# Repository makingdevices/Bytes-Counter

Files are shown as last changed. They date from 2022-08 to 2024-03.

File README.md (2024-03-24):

<!-- Improved compatibility of back to top link: See: https://github.com/othneildrew/Best-README-Template/pull/73 -->

<!--
*** Thanks for checking out the Best-README-Template. If you have a suggestion
*** that would make this better, please fork the repo and create a pull request
*** or simply open an issue with the tag "enhancement".
*** Don't forget to give the project a star!
*** Thanks again! Now go create something AMAZING! :D
-->

<!-- PROJECT SHIELDS -->
<!--
*** I'm using markdown "reference style" links for readability.
*** Reference links are enclosed in brackets [ ] instead of parentheses ( ).
*** See the bottom of this document for the declaration of the reference variables
*** for contributors-url, forks-url, etc. This is an optional, concise syntax you may use.
*** https://www.markdownguide.org/basic-syntax/#reference-style-links
-->
[][ig-url]
[][sponsor-url]
[][stars-url]
[][issues-url]
[][linkedin-url]

<!-- PROJECT LOGO -->
<br />
<div align="center">
  <a href="https://makingdevices.com/links/">
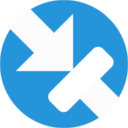
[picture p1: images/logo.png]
    
  </a>

<h3 align="center">Making Devices</h3>

  <p align="center">
    Open Source projects where we struggle with engineering, electronics, coding and who knows what else... In this case, Bytes Counter is a very simple digital tally counter, so hopefully you may find it interesting ;)
  </p>
</div>

<!-- TABLE OF CONTENTS -->
<details>
  <summary>Table of Contents</summary>
  <ol>
    <li>
      <a href="#about-the-project">About The Project</a>
      <ul>
        <li><a href="#built-with">Built With</a></li>
      </ul>
    </li>
    <li>
      <a href="#Build-one">Build one</a>
      <ul>
      </ul>
    </li>
    <li><a href="#usage">Usage</a></li>
    <li><a href="#roadmap">Roadmap</a></li>
    <li><a href="#license">License</a></li>
    <li><a href="#contact">Contact</a></li>
    <li><a href="#Sponsor">Sponsor</a></li>
  </ol>
</details>

<!-- ABOUT THE PROJECT -->
## About The Project

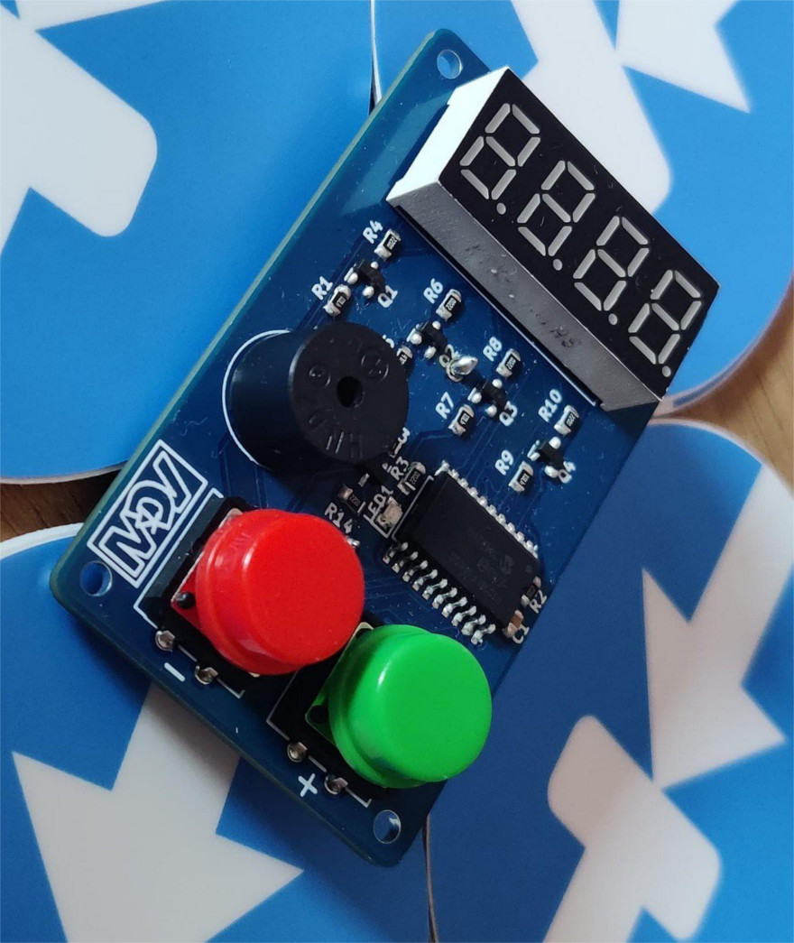
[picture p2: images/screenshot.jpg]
Bytes Counter Shot
[](https://makingdevices.com/Bytes-Counter)

Bytes Counter is a simple Tally Counter for counting people in places, helping you in inventories, practising soldering or just counting things at work! The project was chosen to test some PCB manufacturer capabilities and experiment with both the XLP (Extreme Low-Power Technology) and the pic18LF14k50 itself

The PCB does not have any power button, since the project's approach is to use the XLP technology of the PIC. It only has two buttons: increase/decrease the count.

A buzzer helps you count anything without needing to read the display every time so that you can focus on your work.

Even after weeks or months, the count is kept while in deep sleep mode.

<p align="right">(<a href="#readme-top">back to top</a>)</p>

### Built With

[][PIC-url]
[][MPLAB-C-url]
[][kicad-url]
[][sponsor-url]

<p align="right">(<a href="#readme-top">back to top</a>)</p>

<!-- GETTING STARTED -->

## Build one

1. Get the gerber files for the latest version: [V1](https://github.com/makingdevices/Bytes-Counter/blob/main/v1/Gerber/BytesCounterV1.zip) 
2. Send them to a PCB manufacturer ([Our Sponsor is PCBWAY][sponsor-url])
3. Buy all the components from the [Bill Of Materials](https://github.com/makingdevices/Bytes-Counter/blob/main/v1/BytesCounter_BOM.xlsx)
4. Solder everything with the help of the [schematic](https://github.com/makingdevices/Bytes-Counter/blob/main/v1/schematicv1.pdf)
5. Burn the [latest firmware](https://github.com/makingdevices/Bytes-Counter/blob/main/v1/Simulation/Bytes_Counter.hex)
6. Give us a Star to the respository ;)

Here it is an assembly video:

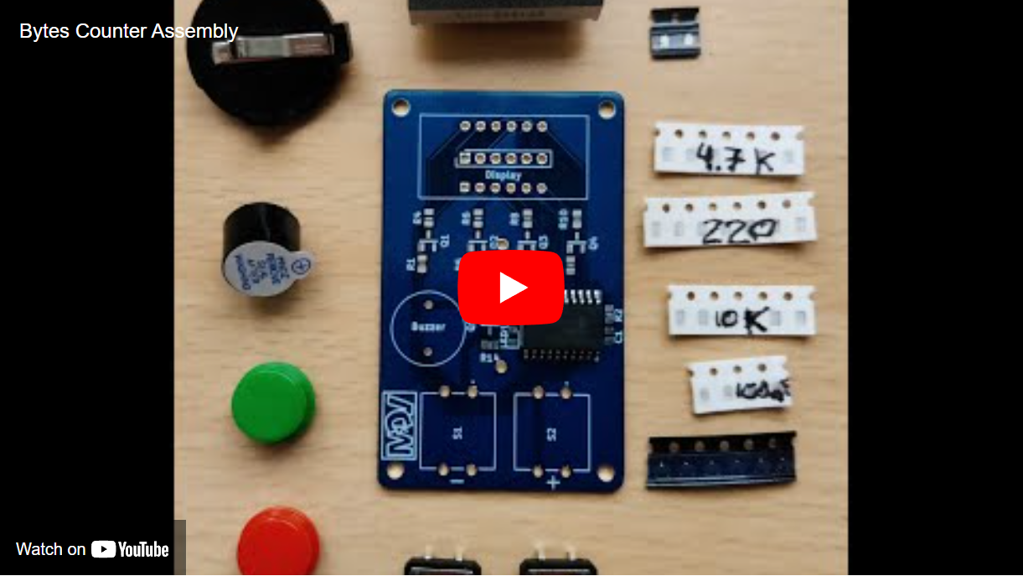
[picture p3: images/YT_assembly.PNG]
Assembly Shot
[](https://www.youtube.com/watch?v=Gu0cR_CFLYs)

<p align="right">(<a href="#readme-top">back to top</a>)</p>

<!-- USAGE EXAMPLES -->
## Usage

Instructions of use:

- Pressing "+" or "-" will increase/decrease the count.
- Long press "+" : Sound Event -> Activate/Deactivate buzzer sounds.
- Long press "-" : Reset event -> Reset the count.
- 60s without pressing any button: Deep Sleep Mode -> Display off.
- Any button pulsation will exit Deep Sleep Mode.

<p align="right">(<a href="#readme-top">back to top</a>)</p>

<!-- ROADMAP -->
## Roadmap

- [x] Count up/down and show it on screen
- [x] enable/disable sound when pressing buttons
- [x] Low Power Consumption
    - [x] Lower the frequency of the microcontroller at minimum
    - [x] Enter deep sleep mode automatically

See the [open issues](https://github.com/makingdevices/Bytes-Counter/issues) for a full list of proposed features (and known issues).

State: Project <b>FINISHED</b> - 01/08/2022

<p align="right">(<a href="#readme-top">back to top</a>)</p>

<!-- LICENSE -->
## License

Distributed under three licenses:
- [Hardware](/License/HW_cern_ohl_s_v2.pdf)
- [Software](/License/SW_GPLv3.0.txt)
- [Documentation](/License/Documentation_CC-BY-SA-4.0.txt)

[GPL v3 License][license-url] 
<p align="right">(<a href="#readme-top">back to top</a>)</p>

<!-- CONTACT -->
## Contact

Making Devices - [@MakingDevices](https://www.instagram.com/makingdevices/)

Project Link: [https://github.com/makingdevices/Bytes-Counter](https://github.com/makingdevices/Bytes-Counter)

Other Links: [LinkTree](https://makingdevices.com/links/)

<p align="right">(<a href="#readme-top">back to top</a>)</p>

<!-- Sponsor -->
## Sponsor

[PCBWAY](https://www.pcbway.com/?from=makingdevices) helped us with the fabrication of the PCBs. You can check their quality with the following pictures:

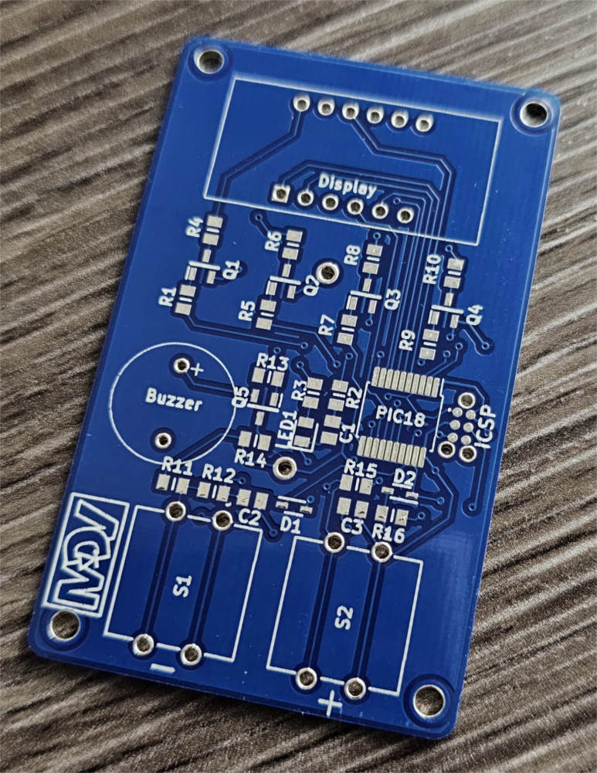
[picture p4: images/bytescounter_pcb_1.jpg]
PCB Shot 1
[](https://www.pcbway.com/?from=makingdevices)
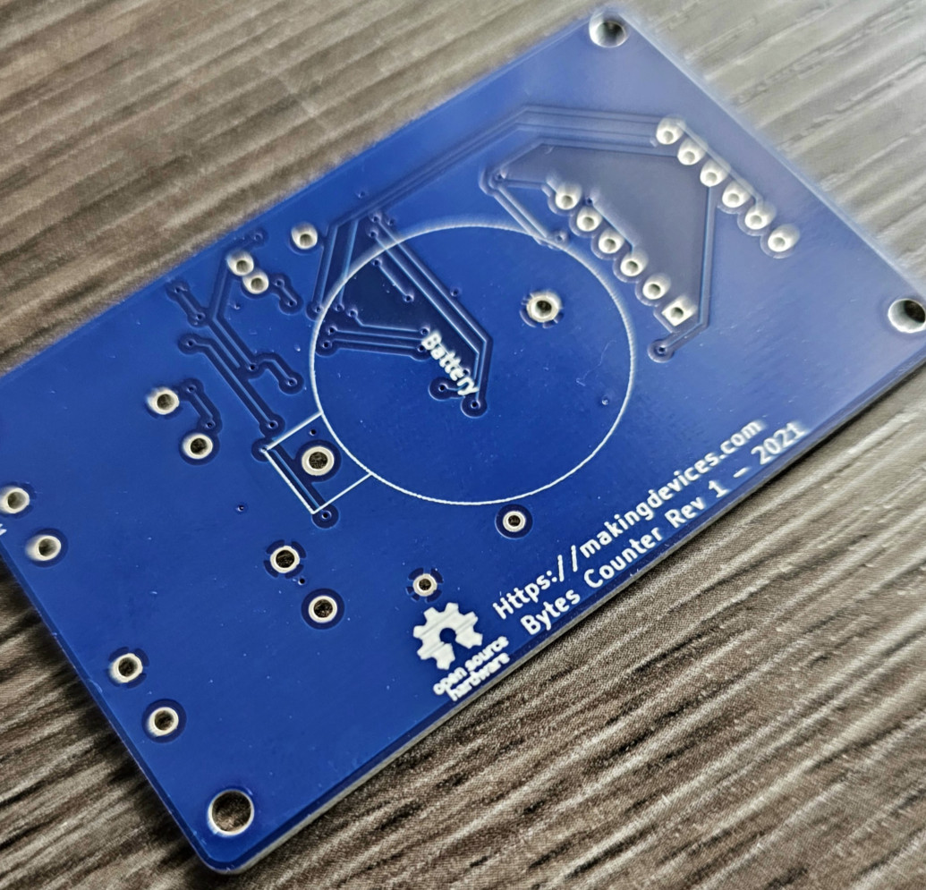
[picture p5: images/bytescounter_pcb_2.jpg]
PCB Shot 2
[](https://www.pcbway.com/?from=makingdevices)

Should you want to colaborate with MakingDevices, you can buy a [BytesCounter fully assembled and ready to use](https://www.pcbway.com/project/gifts_detail/Bytes_Counter_v1_0_4c88cb45.html) ;).

<p align="right">(<a href="#readme-top">back to top</a>)</p>

<!-- MARKDOWN LINKS & IMAGES -->
<!-- https://www.markdownguide.org/basic-syntax/#reference-style-links -->
[contributors-shield]: https://img.shields.io/github/contributors/makingdevices/Bytes-Counter.svg?style=for-the-badge
[contributors-url]: https://github.com/makingdevices/Bytes-Counter/graphs/contributors
[forks-shield]: https://img.shields.io/github/forks/makingdevices/Bytes-Counter.svg?style=for-the-badge
[forks-url]: https://github.com/makingdevices/Bytes-Counter/network/members
[stars-shield]: https://img.shields.io/github/stars/makingdevices/Bytes-Counter.svg?style=for-the-badge
[stars-url]: https://github.com/makingdevices/Bytes-Counter/stargazers
[issues-shield]: https://img.shields.io/github/issues/makingdevices/Bytes-Counter.svg?style=for-the-badge
[issues-url]: https://github.com/makingdevices/Bytes-Counter/issues
[license-shield]: /images/license.png
[license-url]: https://github.com/makingdevices/Bytes-Counter/tree/main/License
[linkedin-shield]: https://img.shields.io/badge/-LinkedIn-black.svg?style=for-the-badge&logo=linkedin&colorB=555
[linkedin-url]: https://www.linkedin.com/company/making-devices/
[sponsor-shield]: https://img.shields.io/badge/SPONSOR-PCBWAY-black.svg?style=for-the-badge&colorB=1200
[sponsor-url]: https://www.pcbway.com/?from=makingdevices
[sponsor-screenshot]: /images/PCB_sponsor.png
[product-screenshot]: images/screenshot.jpg
[pcb_pic1]: images/bytescounter_pcb_1.jpg
[pcb_pic2]: images/bytescounter_pcb_2.jpg
[PIC]: https://img.shields.io/badge/PIC18LF14K50-000000?style=for-the-badge
[PIC-url]: http://ww1.microchip.com/downloads/en/devicedoc/40001350f.pdf
[kicad-shield]: https://img.shields.io/badge/kicad-0b03fc?style=for-the-badge&logo=kicad&logoColor=white
[kicad-url]: https://www.kicad.org/
[YT-screenshot]: images/YT_assembly.PNG
[sponsor-icon]:  https://img.shields.io/badge/-PCBWAY-black.svg?style=for-the-badge&colorB=1200
[ig-shield]: https://img.shields.io/badge/instagram-a83297?style=for-the-badge&logo=instagram&logoColor=white
[ig-url]: https://www.instagram.com/makingdevices/
[MPLAB-C]: https://img.shields.io/badge/MPLAB%20C18-DD0031?style=for-the-badge&logo=C&logoColor=white
[MPLAB-C-url]: https://www.microchip.com/en-us/development-tool/SW006011
[Svelte.dev]: https://img.shields.io/badge/Svelte-4A4A55?style=for-the-badge&logo=svelte&logoColor=FF3E00
[Svelte-url]: https://svelte.dev/
[Laravel.com]: https://img.shields.io/badge/Laravel-FF2D20?style=for-the-badge&logo=laravel&logoColor=white
[Laravel-url]: https://laravel.com
[Bootstrap.com]: https://img.shields.io/badge/Bootstrap-563D7C?style=for-the-badge&logo=bootstrap&logoColor=white
[Bootstrap-url]: https://getbootstrap.com
[JQuery.com]: https://img.shields.io/badge/jQuery-0769AD?style=for-the-badge&logo=jquery&logoColor=white
[JQuery-url]: https://jquery.com

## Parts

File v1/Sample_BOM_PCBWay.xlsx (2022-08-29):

 |  |  |  | Bytes Counter v1 BOM (Sample Bill of Materials)
Item # | *Designator | *Qty | Layer | Manufacturer | *Mfg Part # | Description / Value | *Package/Footprint | Type | Your Instructions / Notes | Price
1 | IC1 | 1 | top | Microchip | PIC18LF14K50T-I/SS | MicroProcessor | 20-SSOP | SMD | It has to be the official part
2 | LED1 | 1 | top | TOGIALED | TJ-S2012SW8TGLC2G-A5 | Green LED | 0805 | SMD | It can be replaced for other parts
3 | Q1,Q2,Q3,Q4,Q5 | 5 | top | TOSHIBA | 2SC2712 | NPN transistor 150mA | SOT23-3 | SMD | It can be replaced for other parts
4 | R3, R14 | 2 | top | RALEC | RTT052200FTP | 220 Ohm Resistor / 125mW | 0805 | SMD | It can be replaced for other parts
5 | R4, R6, R8, R10 | 4 | top | YAGEO | RC0805FR-7W100RL | 100 Ohm Resistor / 250mW | 0805 | SMD | It can be replaced for other parts
6 | R1, R5, R7, R9, R13 | 5 | top | RALEC | RTT054701FTP | 4.7k Ohm Resistor / 125mW | 0805 | SMD | It can be replaced for other parts
7 | R2, R11, R12, R15, R16 | 5 | top | YAGEO | RT0805CRD0710KL | 10K Ohm Resistor / 125mW | 0805 | SMD | It can be replaced for other parts
8 | C1, C2, C3 | 3 | top | YAGEO | AC0805KRX7R9BB104 | 100nF Capacitor 50V | 0805 | SMD | It can be replaced for other parts
9 | D1, D2 | 2 | top | BAS170WS-E3-08 | Vishay Intertech | 70V Schottky diode | SOD-323-2 | SMD | It can be replaced for other parts
10 | S1, S2 | 2 | top | Diptronics | DTS-21K-V | Buttons | 4POS | thru-hole | It can be replaced for other parts
11 | U2 | 1 | Bottom | AAA-BAT-029-K01 | LOTES | 2032 Battery Holder | 2POS | thru-hole | It can be replaced for other parts
12 | U1 | 1 | top | FJ3461AH | Shenzhen Zhihao Elec | Display | 12POS | thru-hole | It can be replaced for other parts
13 | LS1 | 1 | top | Jiangsu Huaneng Elec | TMB12A05 | Buzzer | 2POS | thru-hole | It can be replaced for other parts
 | Total: | 33 |  |  |  |  |  |  | Total:

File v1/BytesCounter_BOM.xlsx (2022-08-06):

Part | Info | Qty. | Unit Price | Ext. Price | LSCS | Link
PIC18LF14K50-I/PT | MicroProcessor | 1 | $2.0000 | $2.0000 | C219580 | https://lcsc.com/product-detail/Others_Microchip-Tech_PIC18F45K50-I-PT_Microchip-Tech-PIC18F45K50-I-PT_C219580.html
PCB v1 | PCBWAY | 1 | $3.0000 | $3.0000 |  | https://www.pcbway.com
TJ-S2012SW8TGLC2G-A5 | Green LED | 1 | $0.0291 | $0.0291 | C192319 | https://lcsc.com/product-detail/Others_TOGIALED-TJ-S2012SW8TGLC2G-A5_C192319.html
MMBT5551LT1G | NPN 600mA | 5 | $0.0250 | $0.1250 | C41095 | https://lcsc.com/product-detail/Bipolar-Transistors-BJT_ON-Semiconductor-ON-MMBT2222ALT3G_C416011.html
RTT052200FTP | 220 Ohm 0805 | 2 | $0.0024 | $0.0049 | C104105 | https://lcsc.com/product-detail/Chip-Resistor-Surface-Mount_220R-2200-1_C104105.html
NQ05W8J0101T5E | 100 Ohm 0805 | 4 | $0.0035 | $0.0140 | C965100
RTT054701FTP | 4.7k Ohm 0805 | 5 | $0.0042 | $0.0208 | C104344 | https://lcsc.com/product-detail/Chip-Resistor-Surface-Mount_4-7KR-4701-1_C104344.html
0805W8F1002T5E | 10K 0805 | 5 | $0.0028 | $0.0138 | C38522 | https://lcsc.com/product-detail/Chip-Resistor-Surface-Mount_UNI-ROYAL-Uniroyal-Elec-0805W8F1002T5E_C38522.html
TMB12A05 | Buzzer 5V | 1 | $0.1893 | $0.1893 | C96093 | https://lcsc.com/product-detail/Buzzers_Jiangsu-Huaneng-Elec-TMB12A05_C96093.html
AC0805KRX7R9BB104 | 0.1uF Cap | 3 | $0.0198 | $0.0594 | C277502 | https://lcsc.com/product-detail/Others_YAGEO-AC0805KRX7R9BB104_C277502.html
cr2032 battery holder | 2032 Battery Holder | 1 | $0.0700 | $0.0700 |  | https://es.aliexpress.com/item/33029764816.html
3461AS | Display | 1 | $0.1900 | $0.1900 |  | https://es.aliexpress.com/item/32795459724.html?spm=a2g0s.9042311.0.0.274263c0RaCynT
Tactile Push Buttons | Buttons | 2 | $0.0750 | $0.1500 |  | https://www.banggood.com/200Pcs-Tactile-Push-Button-Switch-Momentary-Tact-Caps-p-1562278.html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
ZLLS410TA | Diodes | 2 | $0.2391 | $0.4782 | C177096 | https://lcsc.com/product-detail/Schottky-Barrier-Diodes-SBD_Diodes-Incorporated-ZLLS410TA_C177096.html
 |  |  |  | Total: | $5.8663

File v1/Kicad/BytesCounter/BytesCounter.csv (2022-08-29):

Source: | C:\Users\rubenelportero\Desktop\Making Devices\Projects\Bytes Counter\v1\Kicad\BytesCounter\BytesCounter.sch
Date: | 19/08/2022 09:49:35
Tool: | Eeschema (5.1.12-1-g0a0a2da680)-1
Generator: | C:\Program Files\KiCad\bin\scripting\plugins/bom_csv_grouped_by_value.py
Component Count: | 34
Individual Components:
Item | Qty | Reference(s) | Value | LibPart | Footprint | Datasheet | Allied_Number | Description | Height | Manufacturer_Name | Manufacturer_Part_Number | Mouser Part Number | Mouser Price/Stock | RS Part Number | RS Price/Stock
 |  | C1 | 100nF | BytesCounter-rescue:GCG21BR71H154KA01K-SamacSys_Parts | CAPC2012X145N | https://psearch.en.murata.com/capacitor/product/GCG21BR71H154KA01%23.html |  | Capacitor L=2.0mm W=1.25mm T=1.25mm | 1.45 | Murata Electronics | GCG21BR71H154KA01K
 |  | C2 | 100nF | BytesCounter-rescue:GCG21BR71H154KA01K-SamacSys_Parts | CAPC2012X145N | https://psearch.en.murata.com/capacitor/product/GCG21BR71H154KA01%23.html |  | Capacitor L=2.0mm W=1.25mm T=1.25mm | 1.45 | Murata Electronics | GCG21BR71H154KA01K
 |  | C3 | 100nF | BytesCounter-rescue:GCG21BR71H154KA01K-SamacSys_Parts | CAPC2012X145N | https://psearch.en.murata.com/capacitor/product/GCG21BR71H154KA01%23.html |  | Capacitor L=2.0mm W=1.25mm T=1.25mm | 1.45 | Murata Electronics | GCG21BR71H154KA01K
 |  | D1 | ZLLS410TA | Library_Loader:ZLLS410TA | SOD2513X120N | http://uk.rs-online.com/web/p/products/7515203P |  | Diodes Inc ZLLS410TA, SMT Schottky Diode, 10V 750mA, 3ns, 2-Pin SOD-323 | 1.2 | Diodes Inc. | ZLLS410TA |  |  | 7515203P | http://uk.rs-online.com/web/p/products/7515203P
 |  | D2 | ZLLS410TA | Library_Loader:ZLLS410TA | SOD2513X120N | http://uk.rs-online.com/web/p/products/7515203P |  | Diodes Inc ZLLS410TA, SMT Schottky Diode, 10V 750mA, 3ns, 2-Pin SOD-323 | 1.2 | Diodes Inc. | ZLLS410TA |  |  | 7515203P | http://uk.rs-online.com/web/p/products/7515203P
 |  | IC1 | PIC18LF14K50-I_SO | BytesCounter-rescue:PIC18LF14K50-I_SO-SamacSys_Parts | Package_SO:SSOP-20_5.3x7.2mm_P0.65mm | http://uk.rs-online.com/web/p/products/6669239P | 70047097 | MCU 16K Flash 768 RAM USB 2.0 SOIC20 | 2.65 | Microchip | PIC18LF14K50-I/SO |  |  | 6669239P | http://uk.rs-online.com/web/p/products/6669239P
 |  | J1 | TC2030-MCP-NL | Library_Loader:TC2030-MCP-NL | TC2030-MCP-NL | http://uk.rs-online.com/web/p/products/8252561 |  | TC2030-MCP-NL PCB Footprint (no legs) |  | Microchip | TC2030-MCP-NL |  |  | 8252561 | http://uk.rs-online.com/web/p/products/8252561
 |  | LED1 | LTST-C171GKT | BytesCounter-rescue:LTST-C171GKT-SamacSys_Parts | LEDC2012X90N | http://uk.rs-online.com/web/p/products/6920935P |  | Lite-On LTST-C171GKT, CHIPLED 0805 569 nm Green LED, 2012 (0805) SMD package | 0.9 | Lite-On | LTST-C171GKT |  |  | 6920935P | http://uk.rs-online.com/web/p/products/6920935P
 |  | LS1 | TMB12A05 | BytesCounter-rescue:TMB12A05-SamacSys_Parts | TMB12A05 | https://datasheet.lcsc.com/szlcsc/Jiangsu-Huaneng-Elec-TMB12A05_C96093.pdf |  | 12*9.5 Buzzers RoHS | 9.5 | Jiangsu Huaneng Elec | TMB12A05
 |  | Q1 | SMMBT5551LT1G | BytesCounter-rescue:SMMBT5551LT1G-SamacSys_Parts | SOT96P237X111-3N | http://uk.rs-online.com/web/p/products/1841498P | 70300580 | NPN Bipolar Transistor, 600 mA 160 V, 3-pin SOT-23 | 1.11 | ON Semiconductor | SMMBT5551LT1G |  |  | 1841498P | http://uk.rs-online.com/web/p/products/1841498P
 |  | Q2 | SMMBT5551LT1G | BytesCounter-rescue:SMMBT5551LT1G-SamacSys_Parts | SOT96P237X111-3N | http://uk.rs-online.com/web/p/products/1841498P | 70300580 | NPN Bipolar Transistor, 600 mA 160 V, 3-pin SOT-23 | 1.11 | ON Semiconductor | SMMBT5551LT1G |  |  | 1841498P | http://uk.rs-online.com/web/p/products/1841498P
 |  | Q3 | SMMBT5551LT1G | BytesCounter-rescue:SMMBT5551LT1G-SamacSys_Parts | SOT96P237X111-3N | http://uk.rs-online.com/web/p/products/1841498P | 70300580 | NPN Bipolar Transistor, 600 mA 160 V, 3-pin SOT-23 | 1.11 | ON Semiconductor | SMMBT5551LT1G |  |  | 1841498P | http://uk.rs-online.com/web/p/products/1841498P
 |  | Q4 | SMMBT5551LT1G | BytesCounter-rescue:SMMBT5551LT1G-SamacSys_Parts | SOT96P237X111-3N | http://uk.rs-online.com/web/p/products/1841498P | 70300580 | NPN Bipolar Transistor, 600 mA 160 V, 3-pin SOT-23 | 1.11 | ON Semiconductor | SMMBT5551LT1G |  |  | 1841498P | http://uk.rs-online.com/web/p/products/1841498P
 |  | Q5 | SMMBT5551LT1G | BytesCounter-rescue:SMMBT5551LT1G-SamacSys_Parts | SOT96P237X111-3N | http://uk.rs-online.com/web/p/products/1841498P | 70300580 | NPN Bipolar Transistor, 600 mA 160 V, 3-pin SOT-23 | 1.11 | ON Semiconductor | SMMBT5551LT1G |  |  | 1841498P | http://uk.rs-online.com/web/p/products/1841498P
 |  | R1 | 4k7 | BytesCounter-rescue:KTR10EZPF4220-SamacSys_Parts | RESC2012X65N | http://rohmfs.rohm.com/en/products/databook/datasheet/passive/resistor/chip_resistor/ktr.pdf |  | ROHM 0805 Resistor Chip | 0.65 | ROHM Semiconductor | KTR10EZPF4220
 |  | R2 | 10k | BytesCounter-rescue:KTR10EZPF4220-SamacSys_Parts | RESC2012X65N | http://rohmfs.rohm.com/en/products/databook/datasheet/passive/resistor/chip_resistor/ktr.pdf |  | ROHM 0805 Resistor Chip | 0.65 | ROHM Semiconductor | KTR10EZPF4220
 |  | R3 | 220 | BytesCounter-rescue:KTR10EZPF4220-SamacSys_Parts | RESC2012X65N | http://rohmfs.rohm.com/en/products/databook/datasheet/passive/resistor/chip_resistor/ktr.pdf |  | ROHM 0805 Resistor Chip | 0.65 | ROHM Semiconductor | KTR10EZPF4220
 |  | R4 | 100 | BytesCounter-rescue:KTR10EZPF4220-SamacSys_Parts | RESC2012X65N | http://rohmfs.rohm.com/en/products/databook/datasheet/passive/resistor/chip_resistor/ktr.pdf |  | ROHM 0805 Resistor Chip | 0.65 | ROHM Semiconductor | KTR10EZPF4220
 |  | R5 | 4k7 | BytesCounter-rescue:KTR10EZPF4220-SamacSys_Parts | RESC2012X65N | http://rohmfs.rohm.com/en/products/databook/datasheet/passive/resistor/chip_resistor/ktr.pdf |  | ROHM 0805 Resistor Chip | 0.65 | ROHM Semiconductor | KTR10EZPF4220
 |  | R6 | 100 | BytesCounter-rescue:KTR10EZPF4220-SamacSys_Parts | RESC2012X65N | http://rohmfs.rohm.com/en/products/databook/datasheet/passive/resistor/chip_resistor/ktr.pdf |  | ROHM 0805 Resistor Chip | 0.65 | ROHM Semiconductor | KTR10EZPF4220
 |  | R7 | 4k7 | BytesCounter-rescue:KTR10EZPF4220-SamacSys_Parts | RESC2012X65N | http://rohmfs.rohm.com/en/products/databook/datasheet/passive/resistor/chip_resistor/ktr.pdf |  | ROHM 0805 Resistor Chip | 0.65 | ROHM Semiconductor | KTR10EZPF4220
 |  | R8 | 100 | BytesCounter-rescue:KTR10EZPF4220-SamacSys_Parts | RESC2012X65N | http://rohmfs.rohm.com/en/products/databook/datasheet/passive/resistor/chip_resistor/ktr.pdf |  | ROHM 0805 Resistor Chip | 0.65 | ROHM Semiconductor | KTR10EZPF4220
 |  | R9 | 4k7 | BytesCounter-rescue:KTR10EZPF4220-SamacSys_Parts | RESC2012X65N | http://rohmfs.rohm.com/en/products/databook/datasheet/passive/resistor/chip_resistor/ktr.pdf |  | ROHM 0805 Resistor Chip | 0.65 | ROHM Semiconductor | KTR10EZPF4220
 |  | R10 | 100 | BytesCounter-rescue:KTR10EZPF4220-SamacSys_Parts | RESC2012X65N | http://rohmfs.rohm.com/en/products/databook/datasheet/passive/resistor/chip_resistor/ktr.pdf |  | ROHM 0805 Resistor Chip | 0.65 | ROHM Semiconductor | KTR10EZPF4220
 |  | R11 | 10k | BytesCounter-rescue:KTR10EZPF4220-SamacSys_Parts | RESC2012X65N | http://rohmfs.rohm.com/en/products/databook/datasheet/passive/resistor/chip_resistor/ktr.pdf |  | ROHM 0805 Resistor Chip | 0.65 | ROHM Semiconductor | KTR10EZPF4220
 |  | R12 | 10k | BytesCounter-rescue:KTR10EZPF4220-SamacSys_Parts | RESC2012X65N | http://rohmfs.rohm.com/en/products/databook/datasheet/passive/resistor/chip_resistor/ktr.pdf |  | ROHM 0805 Resistor Chip | 0.65 | ROHM Semiconductor | KTR10EZPF4220
 |  | R13 | 4k7 | BytesCounter-rescue:KTR10EZPF4220-SamacSys_Parts | RESC2012X65N | http://rohmfs.rohm.com/en/products/databook/datasheet/passive/resistor/chip_resistor/ktr.pdf |  | ROHM 0805 Resistor Chip | 0.65 | ROHM Semiconductor | KTR10EZPF4220
 |  | R14 | 220 | BytesCounter-rescue:KTR10EZPF4220-SamacSys_Parts | RESC2012X65N | http://rohmfs.rohm.com/en/products/databook/datasheet/passive/resistor/chip_resistor/ktr.pdf |  | ROHM 0805 Resistor Chip | 0.65 | ROHM Semiconductor | KTR10EZPF4220
 |  | R15 | 10k | BytesCounter-rescue:KTR10EZPF4220-SamacSys_Parts | RESC2012X65N | http://rohmfs.rohm.com/en/products/databook/datasheet/passive/resistor/chip_resistor/ktr.pdf |  | ROHM 0805 Resistor Chip | 0.65 | ROHM Semiconductor | KTR10EZPF4220
 |  | R16 | 10k | BytesCounter-rescue:KTR10EZPF4220-SamacSys_Parts | RESC2012X65N | http://rohmfs.rohm.com/en/products/databook/datasheet/passive/resistor/chip_resistor/ktr.pdf |  | ROHM 0805 Resistor Chip | 0.65 | ROHM Semiconductor | KTR10EZPF4220
 |  | S1 | B3F-4050-SamacSys_Parts | BytesCounter-rescue:B3F-4050-SamacSys_Parts-HVolt_sub-system-FIT | B3F-4000 | https://www.omron.com/ecb/products/pdf/en-b3f.pdf |  | lvory Plunger Tactile Switch, SPST-NO 0.05 A@ 24 V dc 3mm |  | Omron Electronics | B3F-4050 | 653-B3F-4050 | https://www.mouser.com/Search/Refine.aspx?Keyword=653-B3F-4050 | 6866768P | http://uk.rs-online.com/web/p/products/6866768P
 |  | S2 | B3F-4050-SamacSys_Parts | BytesCounter-rescue:B3F-4050-SamacSys_Parts-HVolt_sub-system-FIT | B3F-4000 | https://www.omron.com/ecb/products/pdf/en-b3f.pdf |  | lvory Plunger Tactile Switch, SPST-NO 0.05 A@ 24 V dc 3mm |  | Omron Electronics | B3F-4050 | 653-B3F-4050 | https://www.mouser.com/Search/Refine.aspx?Keyword=653-B3F-4050 | 6866768P | http://uk.rs-online.com/web/p/products/6866768P
 |  | U1 | CC56-12EWA | Display_Character:CC56-12EWA | Display_7Segment:CA56-12EWA | http://www.kingbrightusa.com/images/catalog/SPEC/CA56-12EWA.pdf
 |  | U2 | CH075-2032 | BytesCounter-rescue:CH075-2032-SamacSys_Parts | CH0752032 |  |  | RS Pro Battery Holder | 6.6 | RS Components | CH075-2032
Collated Components:
Item | Qty | Reference(s) | Value | LibPart | Footprint | Datasheet | Allied_Number | Description | Height | Manufacturer_Name | Manufacturer_Part_Number | Mouser Part Number | Mouser Price/Stock | RS Part Number | RS Price/Stock
1 | 3 | C1, C2, C3 | 100nF | BytesCounter-rescue:GCG21BR71H154KA01K-SamacSys_Parts | CAPC2012X145N | https://psearch.en.murata.com/capacitor/product/GCG21BR71H154KA01%23.html |  | Capacitor L=2.0mm W=1.25mm T=1.25mm | 1.45 | Murata Electronics | GCG21BR71H154KA01K
2 | 2 | D1, D2 | ZLLS410TA | Library_Loader:ZLLS410TA | SOD2513X120N | http://uk.rs-online.com/web/p/products/7515203P |  | Diodes Inc ZLLS410TA, SMT Schottky Diode, 10V 750mA, 3ns, 2-Pin SOD-323 | 1.2 | Diodes Inc. | ZLLS410TA |  |  | 7515203P | http://uk.rs-online.com/web/p/products/7515203P
3 | 1 | IC1 | PIC18LF14K50-I_SO | BytesCounter-rescue:PIC18LF14K50-I_SO-SamacSys_Parts | Package_SO:SSOP-20_5.3x7.2mm_P0.65mm | http://uk.rs-online.com/web/p/products/6669239P | 70047097 | MCU 16K Flash 768 RAM USB 2.0 SOIC20 | 2.65 | Microchip | PIC18LF14K50-I/SO |  |  | 6669239P | http://uk.rs-online.com/web/p/products/6669239P
4 | 1 | J1 | TC2030-MCP-NL | Library_Loader:TC2030-MCP-NL | TC2030-MCP-NL | http://uk.rs-online.com/web/p/products/8252561 |  | TC2030-MCP-NL PCB Footprint (no legs) |  | Microchip | TC2030-MCP-NL |  |  | 8252561 | http://uk.rs-online.com/web/p/products/8252561
5 | 1 | LED1 | LTST-C171GKT | BytesCounter-rescue:LTST-C171GKT-SamacSys_Parts | LEDC2012X90N | http://uk.rs-online.com/web/p/products/6920935P |  | Lite-On LTST-C171GKT, CHIPLED 0805 569 nm Green LED, 2012 (0805) SMD package | 0.9 | Lite-On | LTST-C171GKT |  |  | 6920935P | http://uk.rs-online.com/web/p/products/6920935P
6 | 1 | LS1 | TMB12A05 | BytesCounter-rescue:TMB12A05-SamacSys_Parts | TMB12A05 | https://datasheet.lcsc.com/szlcsc/Jiangsu-Huaneng-Elec-TMB12A05_C96093.pdf |  | 12*9.5 Buzzers RoHS | 9.5 | Jiangsu Huaneng Elec | TMB12A05
7 | 5 | Q1, Q2, Q3, Q4, Q5 | SMMBT5551LT1G | BytesCounter-rescue:SMMBT5551LT1G-SamacSys_Parts | SOT96P237X111-3N | http://uk.rs-online.com/web/p/products/1841498P | 70300580 | NPN Bipolar Transistor, 600 mA 160 V, 3-pin SOT-23 | 1.11 | ON Semiconductor | SMMBT5551LT1G |  |  | 1841498P | http://uk.rs-online.com/web/p/products/1841498P
8 | 5 | R1, R5, R7, R9, R13 | 4k7 | BytesCounter-rescue:KTR10EZPF4220-SamacSys_Parts | RESC2012X65N | http://rohmfs.rohm.com/en/products/databook/datasheet/passive/resistor/chip_resistor/ktr.pdf |  | ROHM 0805 Resistor Chip | 0.65 | ROHM Semiconductor | KTR10EZPF4220
9 | 5 | R2, R11, R12, R15, R16 | 10k | BytesCounter-rescue:KTR10EZPF4220-SamacSys_Parts | RESC2012X65N | http://rohmfs.rohm.com/en/products/databook/datasheet/passive/resistor/chip_resistor/ktr.pdf |  | ROHM 0805 Resistor Chip | 0.65 | ROHM Semiconductor | KTR10EZPF4220
10 | 2 | R3, R14 | 220 | BytesCounter-rescue:KTR10EZPF4220-SamacSys_Parts | RESC2012X65N | http://rohmfs.rohm.com/en/products/databook/datasheet/passive/resistor/chip_resistor/ktr.pdf |  | ROHM 0805 Resistor Chip | 0.65 | ROHM Semiconductor | KTR10EZPF4220
11 | 4 | R4, R6, R8, R10 | 100 | BytesCounter-rescue:KTR10EZPF4220-SamacSys_Parts | RESC2012X65N | http://rohmfs.rohm.com/en/products/databook/datasheet/passive/resistor/chip_resistor/ktr.pdf |  | ROHM 0805 Resistor Chip | 0.65 | ROHM Semiconductor | KTR10EZPF4220
12 | 2 | S1, S2 | B3F-4050-SamacSys_Parts | BytesCounter-rescue:B3F-4050-SamacSys_Parts-HVolt_sub-system-FIT | B3F-4000 | https://www.omron.com/ecb/products/pdf/en-b3f.pdf |  | lvory Plunger Tactile Switch, SPST-NO 0.05 A@ 24 V dc 3mm |  | Omron Electronics | B3F-4050 | 653-B3F-4050 | https://www.mouser.com/Search/Refine.aspx?Keyword=653-B3F-4050 | 6866768P | http://uk.rs-online.com/web/p/products/6866768P
13 | 1 | U1 | CC56-12EWA | Display_Character:CC56-12EWA | Display_7Segment:CA56-12EWA | http://www.kingbrightusa.com/images/catalog/SPEC/CA56-12EWA.pdf
14 | 1 | U2 | CH075-2032 | BytesCounter-rescue:CH075-2032-SamacSys_Parts | CH0752032 |  |  | RS Pro Battery Holder | 6.6 | RS Components | CH075-2032

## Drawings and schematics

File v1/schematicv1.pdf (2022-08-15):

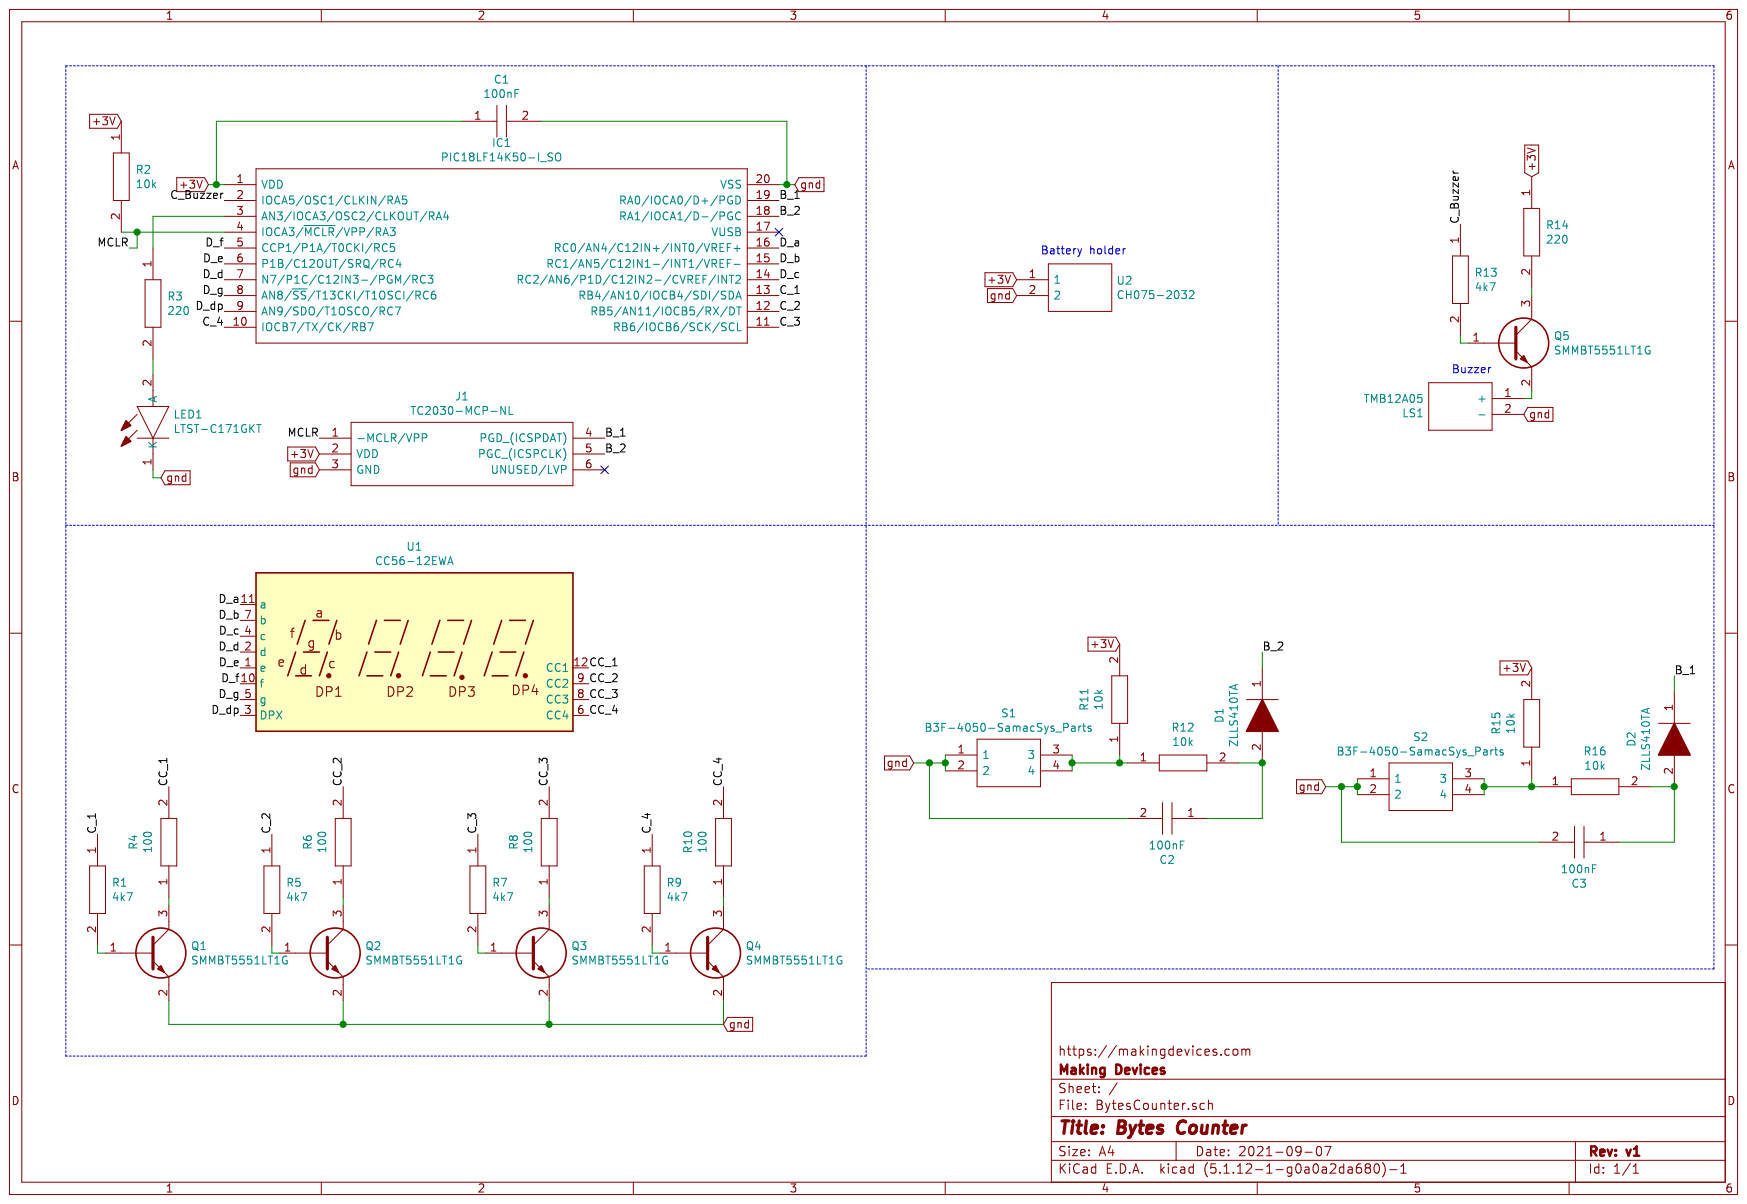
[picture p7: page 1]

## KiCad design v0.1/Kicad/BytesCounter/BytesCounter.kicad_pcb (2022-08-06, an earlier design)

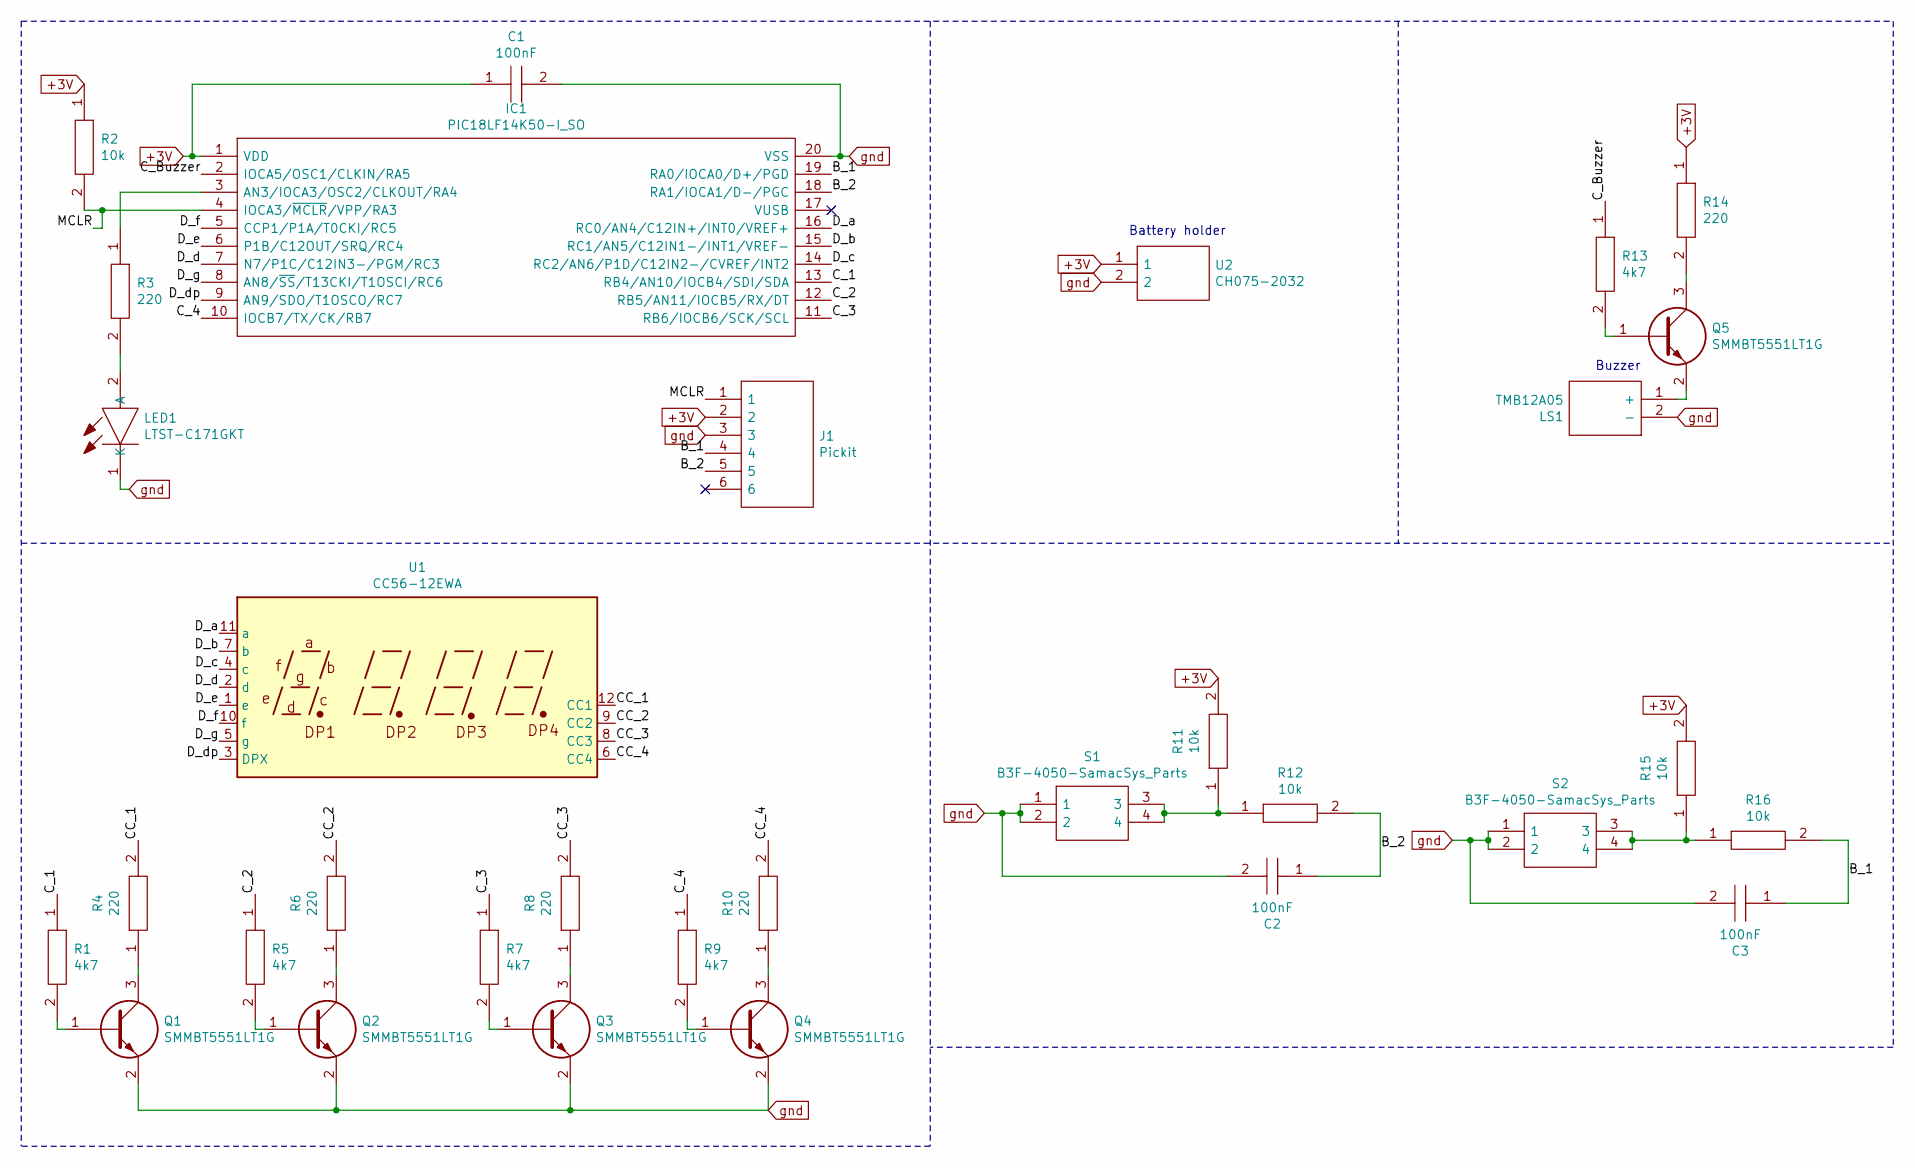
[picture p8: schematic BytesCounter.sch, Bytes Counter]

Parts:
C1, C2, C3: 100nF; CAPC2012X145N; Manufacturer_Part_Number GCG21BR71H154KA01K
IC1: PIC18LF14K50-I_SO; SOIC127P1030X265-20N; Manufacturer_Part_Number PIC18LF14K50-I/SO
J1: Pickit; HDRV6W66P0X254_1X6_1524X254X874P; Manufacturer_Part_Number M20-9990645
LED1: LTST-C171GKT; LEDC2012X90N; Manufacturer_Part_Number LTST-C171GKT
LS1: TMB12A05; Manufacturer_Part_Number TMB12A05
Q1, Q2, Q3, Q4, Q5: SMMBT5551LT1G; SOT96P237X111-3N; Manufacturer_Part_Number SMMBT5551LT1G
R1, R5, R7, R9, R13: 4k7; RESC2012X65N; Manufacturer_Part_Number KTR10EZPF4220
R2, R11, R12, R15, R16: 10k; RESC2012X65N; Manufacturer_Part_Number KTR10EZPF4220
R3, R4, R6, R8, R10, R14: 220; RESC2012X65N; Manufacturer_Part_Number KTR10EZPF4220
S1, S2: B3F-4050-SamacSys_Parts; B3F-4000; Manufacturer_Part_Number B3F-4050; Mouser Part Number 653-B3F-4050
U1: CC56-12EWA; CA56-12EWA
U2: CH075-2032; CH0752032; Manufacturer_Part_Number CH075-2032

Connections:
+3V: C1.1, IC1.1 (VDD), J1.2, R2.1, R11.2, R14.1, R15.2, U2.1
/B_1: C3.1, IC1.19 (RA0/IOCA0/D+/PGD), J1.4, R16.2
/B_2: C2.1, IC1.18 (RA1/IOCA1/D-/PGC), J1.5, R12.2
/CC_1: R4.2, U1.12 (CC1)
/CC_2: R6.2, U1.9 (CC2)
/CC_3: R8.2, U1.8 (CC3)
/CC_4: R10.2, U1.6 (CC4)
/C_1: IC1.13 (RB4/AN10/IOCB4/SDI/SDA), R1.1
/C_2: IC1.12 (RB5/AN11/IOCB5/RX/DT), R5.1
/C_3: IC1.11 (RB6/IOCB6/SCK/SCL), R7.1
/C_4: IC1.10 (IOCB7/TX/CK/RB7), R9.1
/C_Buzzer: IC1.2 (IOCA5/OSC1/CLKIN/RA5), R13.1
/D_a: IC1.16 (RC0/AN4/C12IN+/INT0/VREF+), U1.11 (a)
/D_b: IC1.15 (RC1/AN5/C12IN1-/INT1/VREF-), U1.7 (b)
/D_c: IC1.14 (RC2/AN6/P1D/C12IN2-/CVREF/INT2), U1.4 (c)
/D_d: IC1.7 (N7/P1C/C12IN3-/PGM/RC3), U1.2 (d)
/D_dp: IC1.9 (AN9/SDO/T1OSCO/RC7), U1.3 (DPX)
/D_e: IC1.6 (P1B/C12OUT/SRQ/RC4), U1.1 (e)
/D_f: IC1.5 (CCP1/P1A/T0CKI/RC5), U1.10 (f)
/D_g: IC1.8 (AN8/~SS~/T13CKI/T1OSCI/RC6), U1.5 (g)
/MCLR: IC1.4 (IOCA3/~MCLR~/VPP/RA3), J1.1, R2.2
unnamed: IC1.3 (AN3/IOCA3/OSC2/CLKOUT/RA4), R3.1
unnamed: LED1.2 (A), R3.2
unnamed: LS1.1 (+), Q5.2
unnamed: Q1.1, R1.2
unnamed: Q1.3, R4.1
unnamed: Q2.1, R5.2
unnamed: Q2.3, R6.1
unnamed: Q3.1, R7.2
unnamed: Q3.3, R8.1
unnamed: Q4.1, R9.2
unnamed: Q4.3, R10.1
unnamed: Q5.1, R13.2
unnamed: Q5.3, R14.2
unnamed: R11.1, R12.1, S1.3, S1.4
unnamed: R15.1, R16.1, S2.3, S2.4
gnd: C1.2, C2.2, C3.2, IC1.20 (VSS), J1.3, LED1.1 (K), LS1.2 (-), Q1.2, Q2.2, Q3.2, Q4.2, S1.1, S1.2, S2.1, S2.2, U2.2

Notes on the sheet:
Battery holder
Buzzer

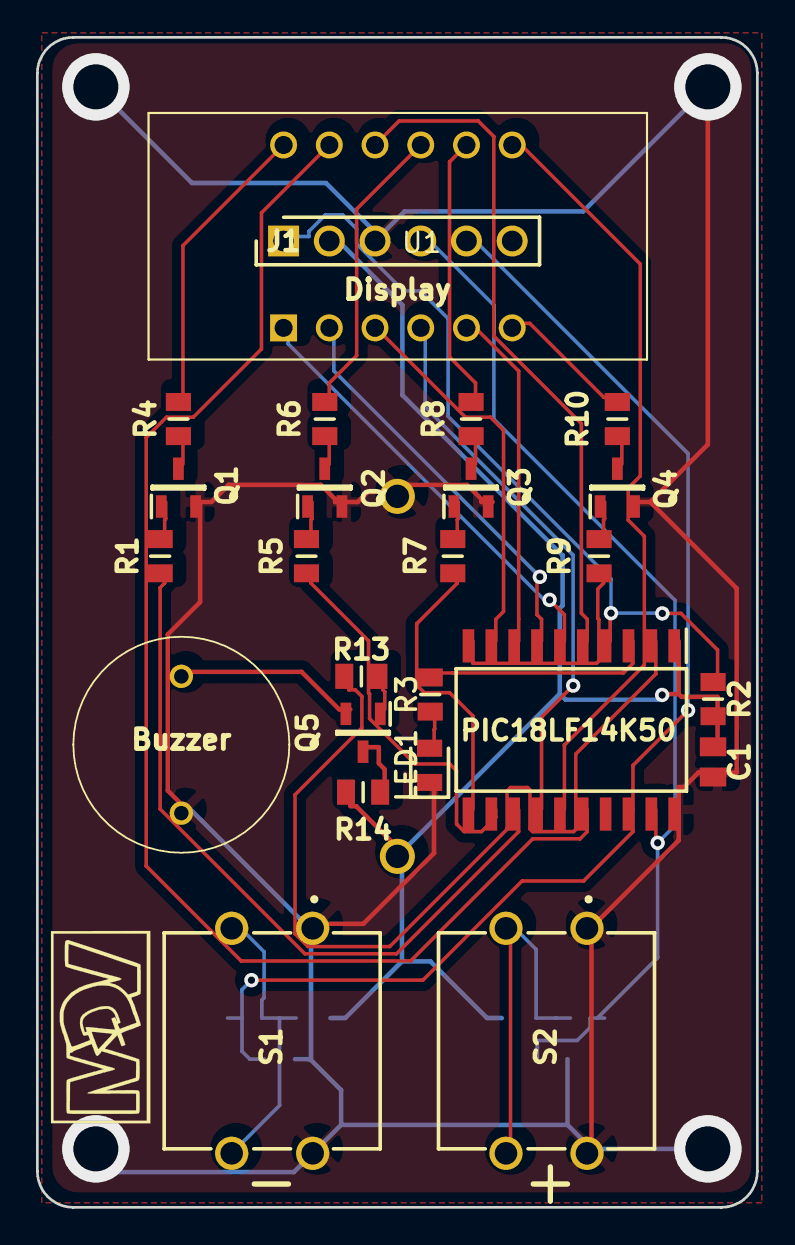
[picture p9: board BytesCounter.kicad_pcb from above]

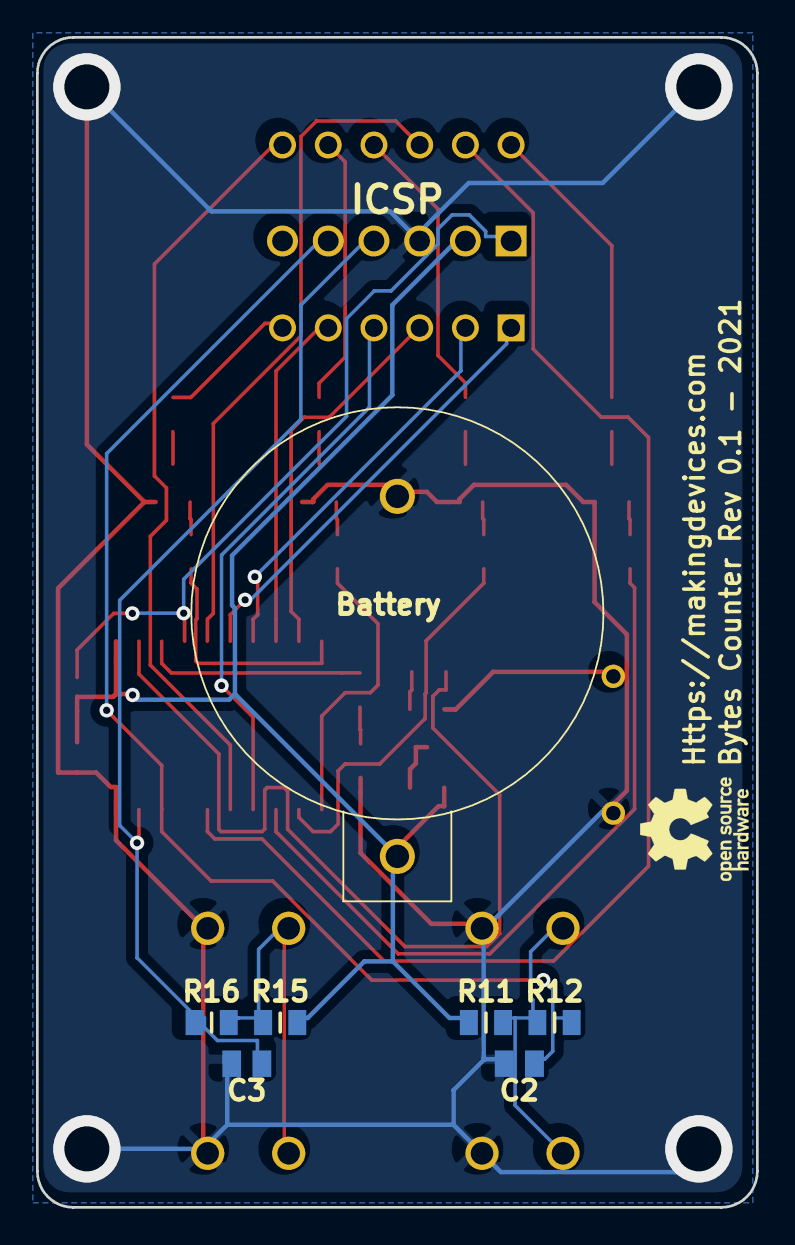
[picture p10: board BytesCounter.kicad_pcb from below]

Board: 2 copper layers, 40.0 x 65.0 mm, 32 parts (7 on the bottom side), 37 nets.

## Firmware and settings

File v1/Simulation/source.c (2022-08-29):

/*	Making Devices 2021
	https://makingdevices.com
	Rubén García Segovia
	Tally Counter
*/

/* Working method

	press + / press - button: Increase/Decrease count

	Long press +: Sound event -> activate/deactivate sound buzzer every button pulsation.
	Long press -: Reset event -> Reset the count.

	60s without pressing any button: Deep Sleep mode -> Display is off and saving mode is activated. The count is keept

	Any button pulsation in Deep Sleep Mode: Count as normal AND reactivate the device. 
*/

#include <p18f13k50.h>
#include <delays.h>

 // setup config bits 
 #pragma config PCLKEN=OFF
 #pragma config FOSC = IRC
 #pragma config BOREN = OFF 
 #pragma config WDTEN = OFF 
 #pragma config LVP = OFF  

char digit = 0;
char const vector[] = {0b00111111,0b00000110,0b01011011,0b01001111,0b01100110,0b01101101,0b01111101,0b00000111,0b01111111,0b01100111,0b01111001}; //Numbers 8-segment codification
char number[] = {0,0,0,0}; //Number Storage
char buzz = 0; //Buzzer counter
int reset = 0; //Reset event counter
int deep_sleep = 0; //Deep Sleep counter
int buzz_reset = 0;  //Enable-disable buzz event counter
char buzz_en = 1; //Buzzer enable
int sleep_time = 10350; //Time before deep sleep
int buzzer_time = 10; //Time for the buzzer sound
int event_timer = 500; //The time we need to mantain pressed the botons to execute reset/sound events.
void InitOSC(void); 
void _low_isr (void);
void _high_isr (void);
void Interrupts_enable (void);

#pragma code low_vector=0x18 //Low interrupt priority starts at 0x18
void low_interrupt(void)
{
_asm goto _low_isr _endasm
}

#pragma code high_vector=0x08 //High interrupt priority starts at 0x08
void high_interrupt(void)
{
_asm goto _high_isr _endasm
}
#pragma code


#pragma interrupt _low_isr

void _low_isr (void){

}

#pragma interrupt _high_isr
void _high_isr (void)   //High priority interrupt.
{
char i=0; 

if(PORTAbits.RA1 == 0){  //If we are pressing one boton...
	reset++; //We increase reset.
	if (reset>event_timer){ //If we have the button pressed for a while...
		buzz = 1;   //We activate buzz and LED
		LATA = 0b00110000;
		number[0] = 0;   //We reset the count.
		number[1] = 0;
		number[2] = 0;
		number[3] = 0;
		reset = 1;
	}
} else{	
	reset = 0; //If we are not pressing nothing, reset = 0.
}
if(PORTAbits.RA0 == 0){  //Same as before with enable-disable buzz event
	buzz_reset++;
	if (buzz_reset>event_timer){
		buzz = 1;
		LATA = 0b00110000;
		buzz_en = !buzz_en;
		buzz_reset = 1;
	}
} else{	
	buzz_reset = 0;
}

if(INTCONbits.TMR0IF) //Timer0 interrupt
	{


//We set the timer0 again
TMR0H = 0xFE;
TMR0L = 0xC7;

	if(buzz > 0) {  //If the buzzer was activated
		buzz++; //increase buzz time
	} 
	if(buzz > buzzer_time) { //If the buzzer has been activated long enough
		buzz = 0;	//we stop the buzzer
		PORTA = 0;
	} 
	LATC = 0; //Turn off the display before changing the number
	switch(digit){  //Print the numbers over the display
		case 3:		//we light the correct display
			LATB = 0b10001111; 
			digit = 0;
			break;
		case 0:
			LATB = 0b01001111; 
			digit = 1;
			break;
		case 1:
			LATB = 0b00101111; 
			digit = 2;
			break;
		case 2:
			LATB = 0b00011111; 
			digit = 3;
			break;
		default:
			break;
	}
	LATC = vector[number[digit]];  //we write the correct number depending on the display.
	INTCONbits.TMR0IF = 0; // reset overflow bit (for timer0).
	}	

 if(INTCONbits.RABIF) //if we are pressing a button...
      { 
	  	deep_sleep = 0; //We restart the deep sleep counter
		OSCCONbits.IDLEN = 1; //Set idle mode. 

		  if(PORTAbits.RA0 == 0 && buzz == 0){ //Increase the number if the "+" button is pressed
			 if(!(number[3] == 9 && number[2] == 9 && number[1] == 9 && number[0] == 9)) number[0]++;
		  	 if(buzz_en == 1) LATA = 0b00100000;
		     buzz = 1;
		  }
			
		  if(PORTAbits.RA1 == 0 && buzz == 0){ //Decrease the number if the "-" button is pressed
			 if(!(number[3] == 0 && number[2] == 0 && number[1] == 0 && number[0] == 0)) number[0]--;
		     if(buzz_en == 1) LATA = 0b00100000;
		     buzz = 1;
		  }	

		  for(i=0; i<4;i++){ //In case a number gets higher than 9
			if(number[i]>9){
				number[i+1]++;
				number[i] = 0;
			}
			if(number[i]<0){ //In case a number gets lower than 0
				number[i+1]--;
				number[i] = 9;
			}
		  }
          INTCONbits.RABIF = 0;	//Clear RAB Interrupt Flag 

		//Note: We also use "buzz" variable as a anti-bounce software method, as we only read the bottons every buzzer_time timer0 events.
      }

	deep_sleep++;  //We increase time before sleep

	if (deep_sleep > sleep_time){ //If the time for sleep has come
		OSCCONbits.IDLEN = 0; //Prepare the microchip for deep sleep.
		LATB = 0b00001111; //turn off the display
	}
}

/* ****************** MAIN ****************** */
char init = 0;
void main(void)
{
	if(init == 0){
		InitOSC();     //Internal OSC 16MHz 
    	Interrupts_enable(); //Enable RA0 & RA1 interrupts
		TRISB =0; //Set port B as output
		TRISC =0; //Set port C as output
		init = 1; //We only run this loop once.
		OSCCONbits.IDLEN = 1; //We activate idle mode.
	}
	Sleep(); //Sleep either idle or deep mode!  
}

 void InitOSC(void) 
 {    
      OSCCON  = 0b10010110;   //Internal 250KHz    
 } 

 void Interrupts_enable(void) 
 {    
	TRISA = 0b11001111; //A port as input
	PORTA = 0;
    INTCON2bits.RABPU = 0; // Enable Pull-UP on port A-B
    INTCON2bits.RABIP = 1; // Change on port = High priority
	IOCA  = 0b00000011;        //Enable Interrupt on Change for Pin 4 of Port A 
    INTCONbits.RABIE = 1;      //Enable RA and RB Port Change Interrupt 

T0CONbits.T08BIT = 0;	//5ms at 250Khz timer 0 interrupt
T0CONbits.T0CS = 0;
T0CONbits.PSA = 1;
TMR0H = 0xFE;
TMR0L = 0xC7;
T0CONbits.TMR0ON = 1;

	RCONbits.IPEN       = 1;    //Enable Interrupt Priorities
    INTCONbits.GIEL     = 1;    //Enable Low Priority Interrupt
    INTCONbits.GIEH     = 1;    //Enable high priority interrupts        
    INTCONbits.TMR0IE   = 1;    //Enable Timer0 Interrupt
	INTCONbits.T0IE     = 1;   
    INTCON2bits.TMR0IP  = 1;    //TMR0 set to low Priority Interrupt
    INTCONbits.TMR0IF = 0;  // T0 int flag bit cleared before starting
    T0CONbits.TMR0ON = 1;   // timer0 START
	INTCONbits.GIE = 1; 		   //Enable all unmasked interrupts   
 } 
 
 

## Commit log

2022-08-06 Project Finished
    [BytesCounter-B_Cu.gbr, BytesCounter-B_Mask.gbr, BytesCounter-B_Paste.gbr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]
2022-08-15 New files
    Schematic
2022-12-19 update folders
    [BytesCounter-B_Cu.gbr, BytesCounter-B_Mask.gbr, BytesCounter-B_Paste.gbr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]
